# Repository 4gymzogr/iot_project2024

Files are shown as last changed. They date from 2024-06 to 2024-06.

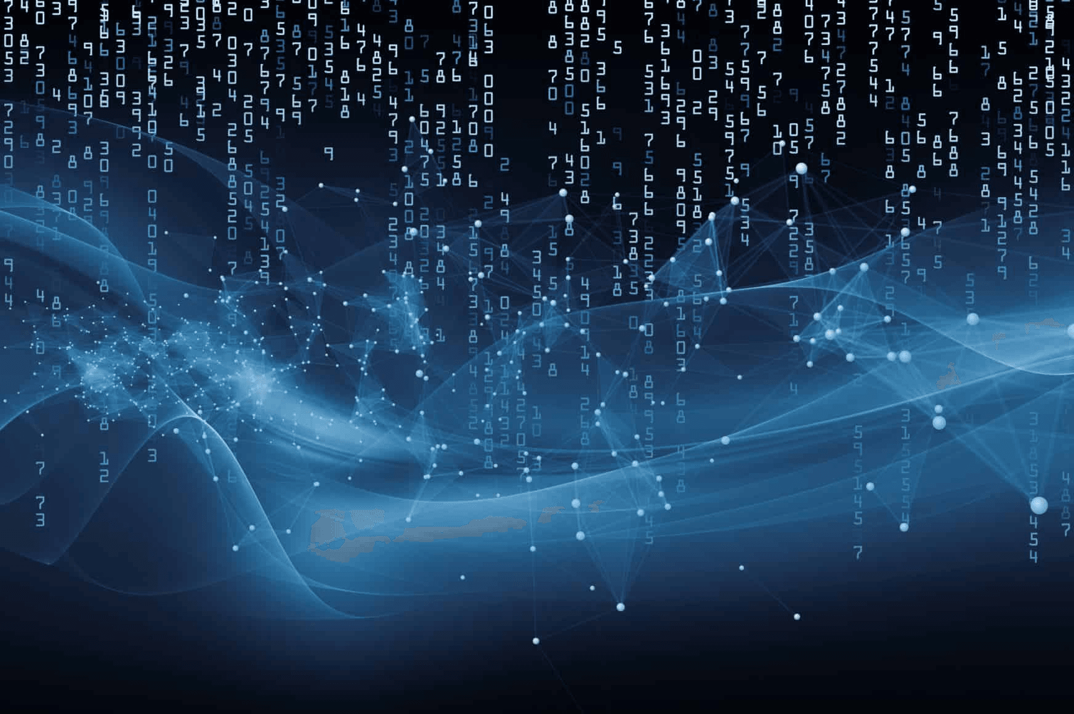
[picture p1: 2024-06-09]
Pictures/poster4.png

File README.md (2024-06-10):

# 4ο Γυμνάσιο Ζωγράφου
## 6ος Πανελλήνιος διαγωνισμός Ανοιχτών τεχνολογιών στην εκπαίδευση ΕΛ/ΛΑΚ 2024

### Θέμα: Έξυπνη τάξη με τεχνολογία ΙοΤ

project1

## Περιληπτική περιγραφή

Ο σκοπός του έργου αυτού, είναι να δημιουργήσουμε ένα δίκτυο σταθμών, μέτρησης της ποιότητας του ατμοσφαιρικού αέρα, 
που επικρατεί μέσα στις αίθουσες διδασκαλίας.<br/> 
Κατά την διάρκεια του σχολικού έτους, παρατηρήσαμε ότι αρκετά παιδιά παραπονιούνται για πονοκεφάλους, χωρίς να υπάρχει κάποιο αίτιο, και έτσι αποφασίσαμε, με την
ομάδα ρομποτικής, να μετρήσουμε την ποιότητα του αέρα, που αναπνέουν οι μαθητές κατά την διάρκεια του μαθήματος.<br/> 
Βρήκαμε ποια είναι τα επιτρεπτά όρια για διάφορους ρύπους, δημιουργήσαμε μια βάση δεδομένων σε postgresql, στην οποία καταγράφουμε τις μετρήσεις από τους σταθμούς ανά λεπτό.<br/> 
Επίσης υλοποιήσαμε κατάλληλους αλγόριθμους, ώστε να υπάρχει ένδειξη μέσα στην αίθουσα, για την ποιότητα του αέρα.<br/> 
Έτσι θα μπορούν οι μαθητές να γνωρίζουν πότε θα πρέπει να ανοίξουν τα παράθυρα για εξαερισμό, με κατάλληλα μηνύματα από τους σταθμούς των μέτρησης.<br/> 



Αρχικά υλοποιήσαμε και τοποθετήσαμε τρεις σταθμούς μέτρησης - χρησιμοποιόντας το Arduino R4 minima - της ποιότητας του ατμοσφαιρικού αέρα, της φωτεινότητας, της θερμοκρασίας, της ατμοσφαιρικής πίεσης και της σχετικής υγρασίας. 
Οι σταθμοί τοποθετήθηκαν στα τμήματα Α1, Β2 και Γ2 του σχολείου μας.
| Αίθουσα  | Σταθμός μέτρησης - Datalogger |
| -- | --- |
| Τμήμα A1  | IMG_20240603_075724027_HDR_1 |
| Τμήμα B2  | |
| Τμήμα Γ2  |  |

Οι μετρήσεις εκπέμπονται από τον κάθε ένα σταθμό, σε μορφή JSON.

{"Temperature":30.34,"Pressure":991.58,"Humidity":33.26,"IAQ":274.53,"Ldr":866}

To JSON αυτό string, μεταδίδεται μέσω συστήματος τεχνολογίας LoRa.<br>

LoRa_1

Κατασκευάσαμε ένα κεντρικό σταθμός βάσης (gateway) - χρησιμοποιόντας το Arduino R4 WiFi - όπως φαίνεται στην παρακάτω εικόνα. <br> Αυτός βρίσκεται στο εργαστήριο πληροφορικής του σχολείου μας. <br> Ο σταθμός αυτός, λαμβάνει τα δεδομένα, μέσω του συστήματος LoRa, κάνει τους απαραίτητους ελέγχους ακεραιότητας και τα στέλνει μέσω του wifi που διαθέτει, στον κεντρικό server του σχολείου μας. <br>



Στον κεντρικό server, έχουμε εγκαταστήσει - πάνω σε ένα Linux virtual machine - τον MQTT broker Mosquitto και την εφαρμογή NodeRED. <br>
O MQTT λαμβάνει τα δεδομένα σε συγκεκριμένα topics για κάθε αίθουσα και τα στέλνει στο NodeRED.
Προγραμματίσαμε κατάλληλα το NodeRED - όπως φαίνεται στην παρακάτω εικόνα - <br>

nodered_1

ώστε τα δεδομένα να εμφανίζονται σε web pages σε γραφικό περιβάλλον, όπως φαίνονται στην παρακάτω εικόνα <br>

web_page_2

Στην σελίδα αυτή έχουμε πρόσβαση ανά πάσα στιγμή με σύνδεσμο που βάλαμε στην  [ιστοσελίδα](https://4gym-zograf.att.sch.gr/) του σχολείου μας.<br>

[Σύνδεσμος](http://zograf4lyk.lserveradmin.gr:1880/ui/#!/0?socketid=U6ivv_HBO9mLjVnQAACe) 

Επίσης το NodeRED προγραμματίστηκε κατάλληλα, ώστε οι τιμές να αποθηκεύονται στη βάση δεδομένων (PostgreSQL database server).<br>

data_base

Προγραμματίσαμε επίσης το NodeRED, ώστε να στέλνει τα δεδομένα στην cloud εφαρμογή για smartphone **BLYNK**. Έτσι έχουμε online παρακολούθηση, σε γραφικό 
περιβάλλον, την κατάσταση που επικρατεί μέσα στις αίθουσες διδασκαλίας. Βλέπουμε επίσης τις χρωματικές ενδείξεις των LEDs που υπάρχουν στους σταθμούς, ανάλογα με την ποιότητα του αέρα που μετράμε. Όταν αυτές είναι στο πορτοκαλί ή στο κόκκινο, σημαίνει ότι πρέπει να εξαερίσουμε την αίθουσα.<br>

blynk_1

## Υλοποίηση του έργου

Το έργο διεξήχθει στις παρακάτω φάσεις:

Α) Διδασκαλία και εκμάθηση της γλώσσας προγραματισμού C++ - εξοικείωση με το Arduino. <br> <br>
Για τον σκοπό αυτό, δημιουργήσαμε για τους συμμετέχοντες μαθητές, κωδικούς για απομακρυσμένη πρόσβαση, στον κεντρικό server του σχολείου μας.
Κεντρικός Server: Dell με CPU XEON x 2, RAM 96GB, αποθηκευτικός χώρος 3ΤΒ ssd. Hypervisor PROXMOX 7.1 με αρκετά LTSP virtuals machines για network boot.  
Σε αυτόν έχουμε εγκαταστήσει το περιβάλλον ανάπτυξης Code::block καθώς και το περιβάλλον ανάπτυξης του μικροελεγκτή Arduino. 
Επίσης έχουμε εγκαταστήσει όλο το Ελεύθερο Λογισμικό Ανοιχτού Κώδικα, που χρησιμοποιήσαμε. Blender για την 3D σχεδίαση των κουτιών, GIMP για την επεξεργασία των φωτογραφιών - σχεδίων,
Fritzing για τον σχεδιασμό των κυκλωμάτων, KiCAD για την σχεδίαση των ηλεκτρονικών κυκλωμάτων, kdenlive για την δημιουργία του video, Libreoffice για τα κείμενα - παρουσιάσεις κλπ.
Έγιναν μαθήματα στην γλώσσα C++ και παράλληλα μάθαιναν προγραμματισμό πάνω στο Αrduino. Χρησιμοποιήθηκε επίσης η πλατφόρμα WokWi για προσομοίωση όλων
των στοιχείων που χρησιμοποιήθηκαν στο έργο μας.

B) Αγορά των υλικών που χρησιμοποιήσαμε στο έργο μας. <br>
| Είδος  | Τύπος | Ποσότητα |
| --- | --- | :---: |
| Μικροελεγκτής  | Arduino R4 Minima - Σταθμοί μέτρησης | 3 |
| Μικροελεγκτής  | Arduino R4 WiFi - Gateway | 1 |
| Αισθητήρας μετεωρολογικών  | BME688 | 3 |
| Αισθητήρας ποιότητας αέρα  | MQ-135 | 3 |
| Αισθητήρας φωτεινότητας  | LDR | 3 |
| Σύστημα μετάδοσης LoRa  | LoRa SX1278 868MHz | 4 |
| Νήματα 3D Εκτυπωτών | PLA+ Filament - 1.75mm 1kg | 3 |
| Πλακέτα συνδέσεων Arduino | Proto Screw Shield-Assembled | 4 |
| Τροφοδοτικό για Arduino | CLW-EB 5V 2A - Output 5.5x2.1 | 5 | 
| Διάφορα άλλα βοηθητικά υλικά | Κόλληση, καλώδια συνδέσεων, θερμοκόλες κλπ | | 

B) Υλοποίηση των κυκλωμάτων των αισθητήρων και προγραμματισμός τους. Αυτό έγινε σταδιακά για τον καθένα ξεχωριστά.<br> <br>

Σταθμός μέτρησης (Arduino R4 minima) <br>
Station1_fritzing_bb

Σταθμός βάσης - gateway (Arduino R4 WiFi) <br>
Gateway_fritzing_bb

Επεξήγηση για την λειτουργία του κάθε αισθητήρα και μορφοποίηση της εμφάνισης των μετρήσεων σε μορφή JSON. <br> <br>
IMG_20240421_123717820_HDR_1
IMG_20240425_132814946_HDR_1
<br> <br>
Γ) Σχεδίαση στο Blender και δημιουργία όλων των υλικών που θα χρησιμοποιηθούν για την συναρμολόγηση των σταθμών μέτρησης, αλλά και του σταθμού βάσης - gateway, από 3D printer.

Screenshot from 2024-06-07 17-14-53_1

Screenshot from 2024-06-07 17-14-27_1

Screenshot from 2024-06-07 17-13-53_1






Δ) Προγραμματισμός των σταθμών των μετρήσεων και τοποθέτησή τους σε ειδικές βάσεις για την εγκατάσταση στις αίθουσες διδασκαλίας.
### Κώδικας Arduino σε C++ για τους σταθμούς μέτρησης αλλά και για τον σταθμό βάσης βρίσκεται στο αποθετήριο του σχολείου μας.

ΣΤ) Προγραμματισμός του Node Red για την εμφάνιση αυτών των μετρήσεων on line στην ιστοσελίδα του σχολείου μας. 
    
Z) Εμφάνιση των μετρήσεων στην εφαρμογή Blynk για smartphones.

[Δείτε το βίντεό μας](https://www.youtube.com/watch?v=hYYW9hXNoDM) 

Στο παραπάνω έργο συμμετέχουν οι μαθητές:
| A/A | Ονοματεπώνυμο  | Τάξη |
| :--: | --- | ---  |
| 1 | Λύκος Γεώργιος	  | Γ’ Γυμνασίου |
| 2 | Κολομπάτσου Χρύσα	  | Α’ Γυμνασίου |
| 3 | Γκίνι Γκάμπριελ	  | Β’ Γυμνασίου |
| 4 | Μπαρμπέρης Παναγιώτης  | Β’ Γυμνασίου |
| 5 | Μπατής Γεώργιος  | Β' Γυμνασίου |
| 6 | Κεφαλά Βασιλική  | Β’ Γυμνασίου |

Υπεύθυνος εκπαιδευτικός:<br>

ΒΕΚΡΑΚΗΣ ΚΩΝΣΤΑΝΤΙΝΟΣ <br>
Καθηγητής Πληροφορικής ΠΕ86

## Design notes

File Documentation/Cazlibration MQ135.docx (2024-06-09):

Calibrating an MQ135 sensor involves establishing a baseline resistance (Ro) value in clean air, which you can then use to calculate gas concentrations accurately. Here's a step-by-step guide on how to calibrate an MQ135 sensor:

1. Prepare the Sensor: Ensure your MQ135 sensor is properly connected to your microcontroller or Arduino board. Connect the sensor's A0 pin to an analog input pin on your microcontroller, and its GND and VCC pins to ground and 5V respectively. Also, ensure that the sensor has been powered up for at least 24-48 hours prior to calibration to stabilize.
2. Choose a Calibration Environment: Find a clean air environment free from any gas pollutants that the MQ135 sensor is designed to detect. This could be outdoors in a rural area or in a well-ventilated room away from any potential sources of pollution.
3. Read Initial Resistance (Ro): Read the analog output from the A0 pin of the MQ135 sensor using the ADC (Analog to Digital Converter) of your microcontroller. Record this initial analog value. This value corresponds to the resistance of the sensor in clean air, which is referred to as Ro.
4. Calculate Ro: Convert the initial analog value into a resistance value using the appropriate formula. The resistance of the sensor in clean air (Ro) can be calculated using the following formula:

Ro = (Resistance at Clean Air * RL) / (ADC Value at Clean Air)

Where:

  - Resistance at Clean Air: Resistance of the load resistor (RL) used in the circuit (typically 10k ohms).
  - RL: Load resistor value.
  - ADC Value at Clean Air: Analog value read from the sensor in clean air.
5. Note Ro Value: Record the calculated Ro value for future reference. This value will be used as the baseline for calculating gas concentrations.
6. Calibration for Specific Gases (Optional): If you're interested in measuring specific gases, you may need to calibrate the sensor further using known concentrations of those gases in a controlled environment. This involves exposing the sensor to different gas concentrations and recording the corresponding analog values to establish calibration curves.
7. Use Ro Value for Gas Concentration Calculation: Once you have the Ro value, you can use it along with the analog readings from the sensor to calculate gas concentrations using appropriate calibration equations provided by the sensor manufacturer.
8. Periodic Calibration: It's essential to periodically recalibrate the MQ135 sensor to ensure accurate readings over time. Factors such as sensor aging and environmental changes can affect its performance.

By following these steps, you can calibrate an MQ135 sensor for air quality monitoring, allowing you to obtain accurate gas concentration readings.

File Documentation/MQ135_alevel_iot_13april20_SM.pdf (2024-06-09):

## NIELIT, Gorakhpur

Course Name: A-level (1st Sem.) | Subject:IoT
Topic: MQ135 interfacing with Arduino | Date: 13.04.2020

In today’s world, we encounter different scenario where we see different gasses being emitted in atmosphere such as home appliances like air conditioner and industrial chimneys. Monitoring of these gasses is very important with safety point of view. Gas Sensors are very helpful in accomplishing this task. Small nose like sensor spontaneously respond to the alteration of gas concentration and keep our systems updated for special tasks.

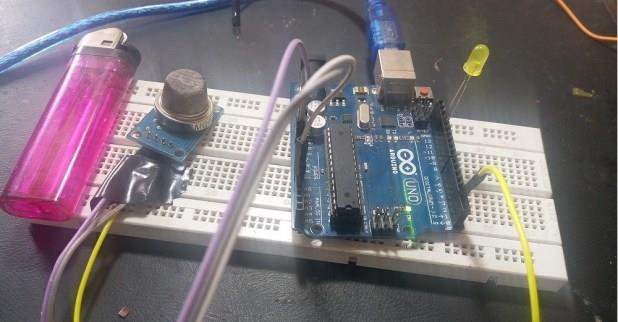
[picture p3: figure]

## What is MQ-135 gas sensor and how does it work?

The gas sensor module consists of a steel exoskeleton under which a sensing element is housed. This sensing element is subjected to current through connecting leads. This current is known as heating current through it, the gases coming close to the sensing element get ionized and are absorbed by the sensing element. This changes the resistance of the sensing element which alters the value of the current going out of it.

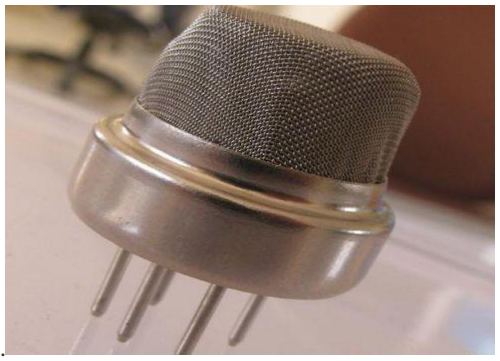
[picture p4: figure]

## Pin Configuration MQ-135 gas sensor

From left to right first pins are as follows:
A0 | Analog output
D0 | Digital output
GND | Ground
Vcc | Supply (5V)

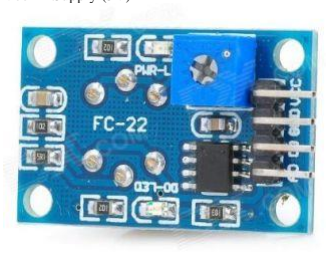
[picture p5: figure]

## Specifications of MQ-135 gas sensor

- Wide detecting scope
- Fast response and High sensitivity
- Stable and long-life Simple drive circuit
- Used in air quality control equipment for buildings/offices, is suitable for detecting of NH3, NOx, alcohol, Benzene, smoke, CO2, etc.
- Size: 35mm x 22mm x 23mm (length x width x height)
- Working voltage: DC 5 V
- Signal output instruction.
- Dual signal output (analog output, and high/low digital output)
- 0 ~ 4.2V analog output voltage, the higher the concentration the higher the voltage.

interfacing of MQ-135 gas sensor with Arduino

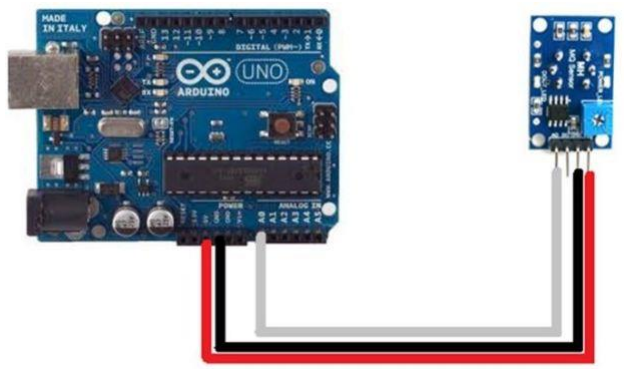
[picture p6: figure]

When no gas digital output is 1 and analog output gives 1023 max value. When gas is present digital output is 0 and analogue output is much less than 1023. Using potentiometer on chip we can control the turning OFF point of digital pin at some value of analog pin. The sensor needs a load-resistor at the output to ground. Its value could be from 2kOhm to 47kOhm. The lower the value, the less sensitive is the sensor. The higher the value, the less accurate is sensor for higher concentrations of gas. If only one specific gas is measured, the load-resistor can be calibrated by applying a known concentration of that gas. If the sensor is used to measure any gas (like in a air quality detector) the load-resistor could be set for a value of about 1V output with clean air. Choosing a good value for the load-resistor is only valid after the burn-in time

NOTE: Don’t touch the sensor, it will be very hot.
Testing the Circuit:
1. After hardware connection, insert the sample sketch into the Arduino IDE.
2. Using a USB cable, connect the ports from the Arduino to the computer.
3. Upload the program.
4. See the results in the serial monitor.

## Code for interfacing of MQ-135 gas sensor with Arduino

int sensorValue;
int digitalValue;
void setup()
{

Serial.begin(9600); // sets the serial port to 9600 pinMode(13, OUTPUT);
pinMode( 3, INPUT);

}

void loop()

{

sensorValue = analogRead(0); // read analog input pin 0

digitalValue = digitalRead(2);
if(sensorValue>400)
{
digitalWrite(13, HIGH);
}
else
digitalWrite(13, LOW);
Serial.println(sensorValue, DEC); // prints the value read Serial.println(digitalValue, DEC);

delay(1000); // wait 100ms for next reading

}

Result:
On serial monitor you can see values of analog pin being detected. Currently in my case they are around about 150 which indicate normal air.
- Normal air returns approximately 100-150
- Alcohol returns approximately 700
- Lighter gas returns approximately 750

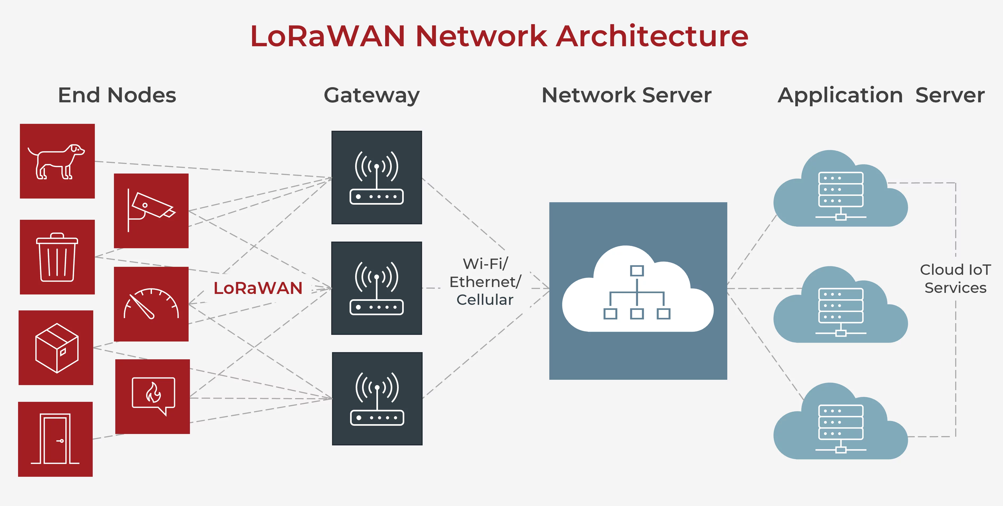
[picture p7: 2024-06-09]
Pictures/LoRaWAN-Network-Architecture.webp

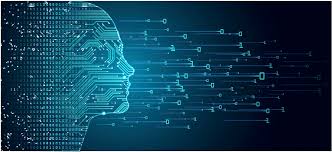
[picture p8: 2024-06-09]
Pictures/poster5.jpeg

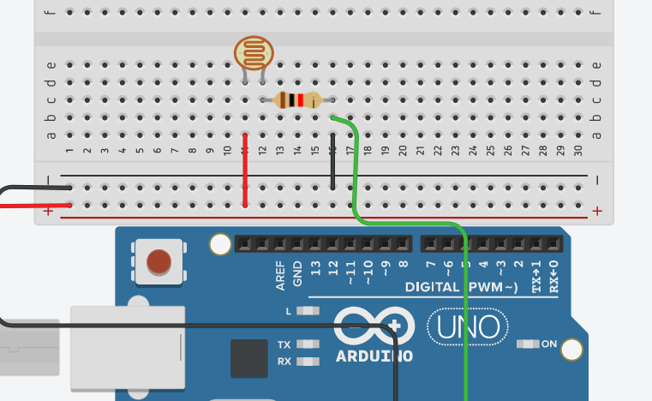
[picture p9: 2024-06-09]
Pictures/LDRConnection.png

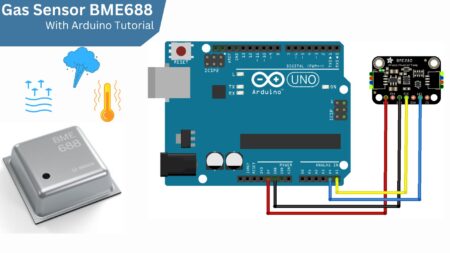
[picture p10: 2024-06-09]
Pictures/BME6882.jpg

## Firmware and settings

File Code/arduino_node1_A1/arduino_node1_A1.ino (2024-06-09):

#include <LoRa.h>
#include <MQ135.h>
#include "bsec.h"

// set serial communication speed
#define SERIAL_BAUD   115200
#define GATEWAY   0xDD
//#define NODE      0xAA
//#define NODE      0xBB
#define NODE      0xCC
#define PIN_MQ135 A0
#define GREENLED    7
#define YELLOWLED   6
#define REDLED      5



// Global variables
unsigned int ldr, dataLength;
byte byte1, byte2;
char*   total;
String output, json_msg = "";
int greenLed, yellowLed, redLed;


// Functions declarations
void checkIaqSensorStatus(void);
void errLeds(void);
void sendMessage(String, byte, byte, byte, byte);
String create_json(void);
void InitBME688();
void InitLoRaRFM95();


// Create objects
Bsec iaqSensor;
MQ135 mq135_sensor(PIN_MQ135);

void InitBME688() {
  // Start BME688 IAQ sensor
  Serial.println("Attempting to init BME688...");
  iaqSensor.begin(BME68X_I2C_ADDR_HIGH, Wire);
  checkIaqSensorStatus();
  bsec_virtual_sensor_t sensorList[13] = {
    BSEC_OUTPUT_IAQ,
    BSEC_OUTPUT_STATIC_IAQ,
    BSEC_OUTPUT_CO2_EQUIVALENT,
    BSEC_OUTPUT_BREATH_VOC_EQUIVALENT,
    BSEC_OUTPUT_RAW_TEMPERATURE,
    BSEC_OUTPUT_RAW_PRESSURE,
    BSEC_OUTPUT_RAW_HUMIDITY,
    BSEC_OUTPUT_RAW_GAS,
    BSEC_OUTPUT_STABILIZATION_STATUS,
    BSEC_OUTPUT_RUN_IN_STATUS,
    BSEC_OUTPUT_SENSOR_HEAT_COMPENSATED_TEMPERATURE,
    BSEC_OUTPUT_SENSOR_HEAT_COMPENSATED_HUMIDITY,
    BSEC_OUTPUT_GAS_PERCENTAGE
  };
  iaqSensor.updateSubscription(sensorList, 13, BSEC_SAMPLE_RATE_LP);
  checkIaqSensorStatus();
  Serial.println("BME688 initializing sensor Ok!");
}


void InitLoRaRFM95() {
  // Start LoRa RFM95 communicator
  Serial.println("Attempting to init LoRaRFM95...");
  int n = 0;
  while (n < 10) {
    if (!LoRa.begin(868E6)) {
      Serial.println("Starting LoRa failed!");
    }
    else {
      Serial.println("LoRa RFM95 initializing Ok!");
      delay(1000);
      break;
    }
    delay(1000);
    n++;
  }
  if (n == 10) {
    Serial.println("LoRa RFM95 initializing failed.");
    while(true);
  }
}


float GetDataFromMQ135(float temperature, float humidity) {
  float rzero = mq135_sensor.getRZero();
  float correctedRZero = mq135_sensor.getCorrectedRZero(temperature, humidity);
  float resistance = mq135_sensor.getResistance();
  float ppm = mq135_sensor.getPPM();
  float correctedPPM = mq135_sensor.getCorrectedPPM(temperature, humidity);

  /*Serial.print("MQ135 RZero: ");
  Serial.print(rzero);
  Serial.print("\t Corrected RZero: ");
  Serial.print(correctedRZero);
  Serial.print("\t Resistance: ");
  Serial.print(resistance);
  Serial.print("\t PPM: ");
  Serial.print(ppm);
  Serial.print("\t Corrected PPM: ");
  Serial.print(correctedPPM);
  Serial.println("ppm");*/

  if (correctedPPM <= 150){
    greenLed = HIGH;
    yellowLed = LOW;
    redLed = LOW;
  } else if(correctedPPM <= 400) {
    greenLed = LOW;
    yellowLed = HIGH;
    redLed = LOW;
  } else {
    greenLed = LOW;
    yellowLed = LOW;
    redLed = HIGH;
  }
  digitalWrite(GREENLED, greenLed);
  digitalWrite(YELLOWLED, yellowLed);
  digitalWrite(REDLED, redLed);

  return correctedPPM;
}


void setup() {
  pinMode( GREENLED, OUTPUT);
  pinMode( YELLOWLED, OUTPUT);
  pinMode( REDLED, OUTPUT);
  
  Serial.begin(SERIAL_BAUD);
  //while (!Serial);

  delay(3000);
  InitBME688();
  InitLoRaRFM95();
}


void loop() {
  
  json_msg = create_json();

  // checkSum for errors
  int msgSum = 0;
  for (int i=0; i<json_msg.length(); i++) {
    //msgSum += json_msg.charAt(i)*(i+1);
    msgSum += json_msg.charAt(i);
  }
      
  byte byte1 = msgSum / 256;
  byte byte2 = msgSum % 256;
    
  dataLength = json_msg.length();
  dataLength ++;
      
  //char total[dataLength];
  //memset(total, '\0', sizeof(dataLength));
  //json_msg.toCharArray(total, dataLength);
  Serial.println(json_msg);
  sendMessage(json_msg, byte1, byte2);

  delay(random(3, 7)*1000);
}


// Helper function definitions
void checkIaqSensorStatus(void)
{
  if (iaqSensor.bsecStatus != BSEC_OK) {
    if (iaqSensor.bsecStatus < BSEC_OK) {
      output = "BSEC error code : " + String(iaqSensor.bsecStatus);
      Serial.println(output);
      for (;;)
        errLeds(); /* Halt in case of failure */
    } else {
      output = "BSEC warning code : " + String(iaqSensor.bsecStatus);
      Serial.println(output);
    }
  }

  if (iaqSensor.bme68xStatus != BME68X_OK) {
    if (iaqSensor.bme68xStatus < BME68X_OK) {
      output = "BME68X error code : " + String(iaqSensor.bme68xStatus);
      Serial.println(output);
      for (;;)
        errLeds(); /* Halt in case of failure */
    } else {
      output = "BME68X warning code : " + String(iaqSensor.bme68xStatus);
      Serial.println(output);
    }
  }
}


void errLeds(void)
{
  pinMode(LED_BUILTIN, OUTPUT);
  digitalWrite(LED_BUILTIN, HIGH);
  delay(100);
  digitalWrite(LED_BUILTIN, LOW);
  delay(100);
}


// reads sensors and create json string
String create_json(void) {
  // Read LDR sensor
  ldr = analogRead(A1);

  String json_message = "";

  // If new data is available on BME688
  if (iaqSensor.run()) { 

    float iaq = GetDataFromMQ135(iaqSensor.temperature, iaqSensor.humidity);

    json_message.concat("{\"Temperature\":");
    json_message.concat(String(iaqSensor.temperature));
    json_message.concat(",");
    
    json_message.concat("\"Pressure\":");
    json_message.concat(String(iaqSensor.pressure/100.0));
    json_message.concat(",");

    json_message.concat("\"Humidity\":");
    json_message.concat(String(iaqSensor.humidity));
    json_message.concat(",");

    json_message.concat("\"IAQ\":");
    json_message.concat(String(iaq));
    json_message.concat(",");

    /*json_message.concat("\"CO2\":");
    json_message.concat(String(iaqSensor.co2Equivalent));
    json_message.concat(",");*/

    json_message.concat("\"Ldr\":");
    json_message.concat(String(ldr));
    json_message.concat("}"); 
  } 
  return json_message; 
}


void sendMessage(String json_message, byte b1, byte b2) {
  LoRa.beginPacket();                   // start packet
  LoRa.write(GATEWAY);               // add destination address
  LoRa.write(NODE);                    // add sender address
  //LoRa.write(msgCount);                 // add message ID
  LoRa.write(json_message.length());       // add payload length
  LoRa.write(b1);                       // add signature byte1
  LoRa.write(b2);                       // add signature byte2
  LoRa.print(json_message);                // add payload
  delay(30);
  LoRa.endPacket();                     // finish packet and send it
}

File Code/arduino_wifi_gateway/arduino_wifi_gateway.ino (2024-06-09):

#include <WiFiS3.h>
#include <ArduinoMqttClient.h>
#include <LoRa.h>
#include <NTPClient.h>
#include <time.h>
#include "arduino_secrets.h" 

#define SERIAL_BAUD   115200

#define GATEWAY   0xDD
#define NODE1     0xAA
#define NODE2     0xBB
#define NODE3     0xCC

#define SS    10  // D10
#define RST   9   // D9
#define DIO0   2  // D2

char ssid[] = SECRET_SSID;
char pass[] = SECRET_PASS;
int status = WL_IDLE_STATUS;
bool flag = false;

char daysOfTheWeek[7][12] = {"Sunday", "Monday", "Tuesday", "Wednesday", "Thursday", "Friday", "Saturday"};

// Mqtt connection
WiFiClient wifiClient;
MqttClient mqttClient(wifiClient);

// MQTT parameters
const char broker[] = MQTT_BROKER;
const int port = 1883;
const char node1_topic[] = "topic/node1";
const char node2_topic[] = "topic/node2";
const char node3_topic[] = "topic/node3";

// Nodes identifiers
byte gateway_id = 0xDD;
byte node1_id = 0xAA;
byte node2_id = 0xBB;
byte node3_id = 0xCC;

int recipient;          // recipient address
byte sender;            // sender address
//byte incomingMsgId = LoRa.read();     // incoming msg ID
byte incomingLength;    // incoming msg length
byte sigByte1;          // incoming sigByte1
byte sigByte2;          // incoming sigByte2

String SenderNode, buf = "", incoming = "";
String rssi_buf;

// Tracks the time since last event fired
unsigned long int currentSecs;
unsigned long int previousSecs;
unsigned long int currentMillis;
unsigned int interval = 1, seconds = 0;

// reset the arduino
void(* resetFunc) (void) = 0;


void InitLoRaRFM95() {
  // Connecting to LoRa module
  Serial.println("Attempting to connect LoRa...");

  int n = 0;
  while (n < 10) {
    if (!LoRa.begin(868E6)) {
      Serial.println("Starting LoRa failed!");
    }
    else
    {
      Serial.println("LoRa RFM95 initializing Ok!");
      delay(2000);
      break;
    }
    delay(1000);
    n++;
  }
  if (n >= 10) {
    Serial.println("LoRa RFM95 initializing failed.");
      while (true);
  }
}


void InitWiFi() {
  // check for the WiFi module:
  if (WiFi.status() == WL_NO_MODULE) {
    Serial.println("Communication with WiFi module failed!");
    // don't continue
    while (true);
  }

  // attempt to connect to WiFi network:
  while (status != WL_CONNECTED) {
    Serial.print("Attempting to connect to WPA SSID: ");
    Serial.println(ssid);
    // Connect to WPA/WPA2 network:
    status = WiFi.begin(ssid, pass);

    // wait 10 seconds for connection:
    delay(10000);
  }
  Serial.print("\nConnected to Access Point with IP: ");
  Serial.println(WiFi.localIP());
}


void InitMqtt() {
  // Attempting to establish a connection to the given MQTT brocker
  Serial.print("Attempting to connect to the MQTT broker: ");
  Serial.println(broker);
  if (!mqttClient.connect(broker, port)) {
    Serial.print("MQTT connection failed! Error code = ");
    Serial.println(mqttClient.connectError());

    Serial.println("Soft reset....");
    NVIC_SystemReset(); 
    delay(2000);
  }
  Serial.println("You're connected to the MQTT broker!");
  Serial.println();
}


void onReceive(int packetSize) {
  if (packetSize == 0) return;

  // read four bytes for packet header:
  recipient = LoRa.read();          // recipient address
  sender = LoRa.read();            // sender address
  //byte incomingMsgId = LoRa.read();     // incoming msg ID
  incomingLength = LoRa.read();    // incoming msg length
  sigByte1 = LoRa.read();          // incoming sigByte1
  sigByte2 = LoRa.read();          // incoming sigByte2

  incoming = "";
  rssi_buf = "";
  // read json data
  for (int i = 0; i < packetSize-5; i++) {
    incoming += (char)LoRa.read();
  }

  // print RSSI of packet
  rssi_buf += " with RSSI ";
  rssi_buf += String(LoRa.packetRssi());
  flag = true;
}

void setup() {
  //Initialize serial and wait for port to open:
  Serial.begin(SERIAL_BAUD);
  delay(3000);

  // Connect LoRa, WiFi and MQTT brocker
  InitLoRaRFM95();
  InitWiFi();
  InitMqtt();  

  // set the message receive callback
  mqttClient.onMessage(onMqttMessage);
  
   // subscribe to a topic
  mqttClient.subscribe(node1_topic);
  mqttClient.subscribe(node2_topic);
  mqttClient.subscribe(node3_topic);
   
  // LoRaNow definitions
  // register the receive callback
  LoRa.onReceive(onReceive);
  // put the radio into receive mode
  LoRa.receive();
}


void onMqttMessage(int messageSize) {
  // we received a message, print out the topic and contents
  while (mqttClient.available()) {
    char ch = mqttClient.read();
    buf += ch;
  } 
  //Serial.println(buf);
  buf = "";
}


unsigned int getChecksum() {
  // checkSum for errors
  unsigned int msgSum = 0;
  for (int i=0; i<incoming.length(); i++) {
    //msgSum += incoming.charAt(i)*(i+1);
    msgSum += incoming.charAt(i);
  }
  Serial.println(msgSum);

  return msgSum;
}


void loop() {

  // check the network connection once every 10 seconds:
  if (!wifiClient.connected()) {
    InitWiFi();
    InitMqtt();
  }

  if (flag) {
    unsigned int check_sum = getChecksum();
    byte byte1 = check_sum / 256;
    byte byte2 = check_sum % 256;
    Serial.println(incoming);
    Serial.println("*** Recieved ***");
    Serial.println(sigByte1);
    Serial.println(sigByte2);
    Serial.println("*** Calculating ***");
    Serial.println(byte1);
    Serial.println(byte2);
    
    // check for communication's errors //
    if (byte1 == sigByte1 && byte2 == sigByte2) { 
    
      if (sender == NODE1) {
        
        Serial.print("Class: A1 => ");
        mqttClient.beginMessage(node1_topic);
        mqttClient.print(incoming);
        mqttClient.endMessage();
      }
      else if (sender == NODE2) {
        Serial.print("Class: B2 => ");
        mqttClient.beginMessage(node2_topic);
        mqttClient.print(incoming);
        mqttClient.endMessage();
      }
      else if (sender == NODE3) {
        Serial.print("Class: G2 => ");
        mqttClient.beginMessage(node3_topic);
        mqttClient.print(incoming);
        mqttClient.endMessage();
      }
  
      Serial.print(incoming);
      Serial.println(rssi_buf);
    }
    
    flag = false;
  }

  // call poll() regularly to allow the library to send MQTT keep alive which
  // avoids being disconnected by the broker
  mqttClient.poll();
  delay(1000);
}
